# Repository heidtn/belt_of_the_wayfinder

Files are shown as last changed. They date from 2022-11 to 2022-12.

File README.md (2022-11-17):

# belt of the wayfinder
This project is the design for a belt that uses vibrational motors to tell the wearer where north is.  This has been inspired by many similar projects in the past.  The basic concept is that by always knowing north, the wearer can gain an intuitive understanding of where north is and improve their sense of direction.

This project includes the PCB design, firmware, and mechanical assemblies.

CAD has been designed using Onshape and the link can be found [here](https://cad.onshape.com/documents/3174cd1b7d359cff45b60529/w/59155bcb796c6976c8cc7d48/e/c52ae8d364edc915756cc2c3)

As of this commit, the firmware and hardware have not yet been tested and development is still underway.

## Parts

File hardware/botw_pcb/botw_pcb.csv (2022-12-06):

Value | Reference(s) | Footprint | JLCPCB Part #
1u | C1 | Capacitor_SMD:C_0603_1608Metric | C15849
10u | C2, C4, C5, C6, C7, C8, C9, C10, C16 | Capacitor_SMD:C_0603_1608Metric | C19702
0.1u | C3 | Capacitor_SMD:C_0603_1608Metric | C14663
220n | C11 | Capacitor_SMD:C_0603_1608Metric | C21120
100n | C12, C13, C14, C15 | Capacitor_SMD:C_0603_1608Metric | C14663
1N4148 | D1, D2, D4, D5, D6, D7, D8, D9 | Diode_SMD:D_SOD-123 | C81598
LED | D3 | LED_SMD:LED_0603_1608Metric | C165982
LED | D10 | LED_SMD:LED_0603_1608Metric | C138547
LED | D11 | LED_SMD:LED_0603_1608Metric | C138545
2.2u | L1 | Inductor_SMD:L_0805_2012Metric | C1043
USB_C_Plug_USB2.0 | P1 | Connector_USB:USB_C_Receptacle_HRO_TYPE-C-31-M-12 | C165948
S8050 | Q1, Q2, Q3, Q4, Q5, Q6, Q7, Q8, Q9 | Package_TO_SOT_SMD:SOT-23 | C2146
300 | R1, R4 | Resistor_SMD:R_0603_1608Metric | C23025
2k | R2 | Resistor_SMD:R_0603_1608Metric | C22975
100 | R3, R5 | Resistor_SMD:R_0603_1608Metric | C22775
200 | R6, R7 | Resistor_SMD:R_0603_1608Metric | C8218
2k2 | R8, R9, R10, R11, R12, R13, R14, R15, R18 | Resistor_SMD:R_0603_1608Metric | C4190
10k | R16, R17 | Resistor_SMD:R_0603_1608Metric | C25804
4k7 | R19, R20 | Resistor_SMD:R_0603_1608Metric | C23162
AAP2154 | U1 | custom_footprints:TSOT-25 | C370749
TPS63001 | U2 | Package_SON:Texas_DRC0010J_ThermalVias | C28060
STM32F030CCTx | U3 | Package_QFP:LQFP-48_7x7mm_P0.5mm | C81787
LIS2MDLTR | U4 | Package_LGA:LGA-12_2x2mm_P0.5mm | C919695
LSM6DS3 | U5 | Package_LGA:LGA-14_3x2.5mm_P0.5mm_LayoutBorder3x4y | C967633

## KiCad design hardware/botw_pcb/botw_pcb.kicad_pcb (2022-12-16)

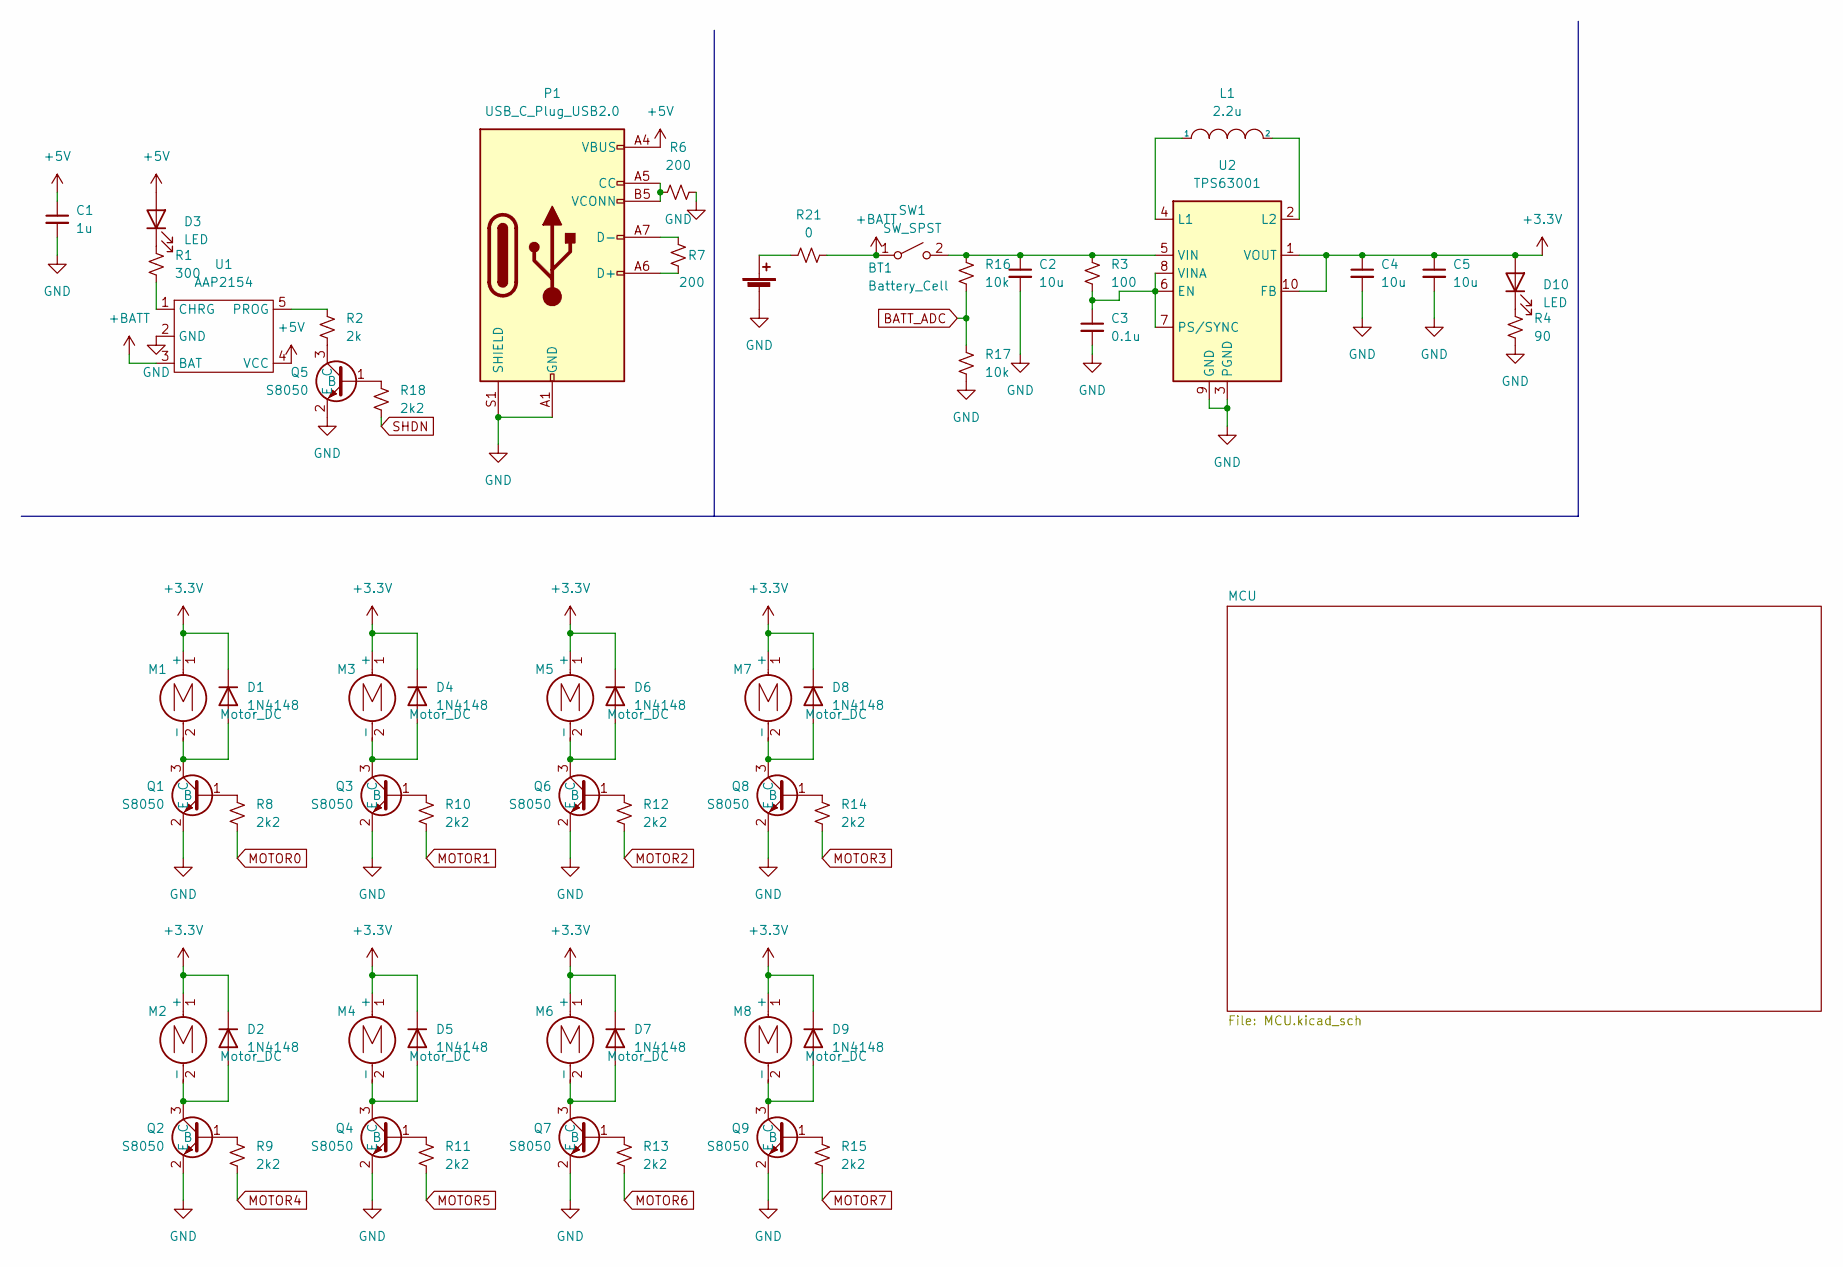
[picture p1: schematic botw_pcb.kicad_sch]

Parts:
BT1: Battery_Cell; PinHeader_1x02_P2.54mm_Vertical
C1: 1u; C_0603_1608Metric
C2, C4, C5: 10u; C_0603_1608Metric
C3: 0.1u; C_0603_1608Metric
D1, D2, D4, D5, D6, D7, D8, D9: 1N4148; D_SOD-123
D3, D10: LED; LED_0603_1608Metric
L1: 2.2u; L_0805_2012Metric
M1, M2, M3, M4, M5, M6, M7, M8: Motor_DC; PinHeader_1x02_P2.54mm_Vertical
P1: USB_C_Plug_USB2.0; USB_C_Receptacle_HRO_TYPE-C-31-M-12
Q1, Q2, Q3, Q4, Q5, Q6, Q7, Q8, Q9: S8050; SOT-23
R1: 300; R_0603_1608Metric
R2: 2k; R_0603_1608Metric
R3: 100; R_0603_1608Metric
R4: 90; R_0603_1608Metric
R6, R7: 200; R_0603_1608Metric
R8, R9, R10, R11, R12, R13, R14, R15, R18: 2k2; R_0603_1608Metric
R16, R17: 10k; R_0603_1608Metric
R21: 0; R_0603_1608Metric
SW1: SW_SPST; PinSocket_1x02_P2.54mm_Vertical
U1: AAP2154; TSOT-25
U2: TPS63001; Texas_DRC0010J_ThermalVias

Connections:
+3.3V: C4.1, C5.1, D1.1 (K), D2.1 (K), D4.1 (K), D5.1 (K), D6.1 (K), D7.1 (K), D8.1 (K), D9.1 (K), D10.2 (A), M1.1 (+), M2.1 (+), M3.1 (+), M4.1 (+), M5.1 (+), M6.1 (+), M7.1 (+), M8.1 (+), U2.1 (VOUT), U2.10 (FB); also elsewhere on the board
+5V: C1.1, D3.2 (A), P1.A4 (VBUS), P1.A9 (VBUS), P1.B4 (VBUS), P1.B9 (VBUS), U1.4 (VCC)
+BATT: R21.2, SW1.1 (A), U1.3 (BAT)
BATT_ADC: R16.2, R17.1; also elsewhere on the board
GND: BT1.2 (-), C1.2, C2.2, C3.2, C4.2, C5.2, P1.A1 (GND), P1.A12 (GND), P1.B1 (GND), P1.B12 (GND), P1.S1 (SHIELD), Q1.2 (E), Q2.2 (E), Q3.2 (E), Q4.2 (E), Q5.2 (E), Q6.2 (E), Q7.2 (E), Q8.2 (E), Q9.2 (E), R4.2, R6.2, R17.2, U1.2 (GND), U2.3 (PGND), U2.9 (GND), U2.11 (PGND); also elsewhere on the board
MOTOR0: R8.2; also elsewhere on the board
MOTOR1: R10.2; also elsewhere on the board
MOTOR2: R12.2; also elsewhere on the board
MOTOR3: R14.2; also elsewhere on the board
MOTOR4: R9.2; also elsewhere on the board
MOTOR5: R11.2; also elsewhere on the board
MOTOR6: R13.2; also elsewhere on the board
MOTOR7: R15.2; also elsewhere on the board
unnamed: BT1.1 (+), R21.1
unnamed: C2.1, R3.1, R16.1, SW1.2 (B), U2.5 (VIN)
unnamed: C3.1, R3.2, U2.6 (EN), U2.7 (PS/SYNC), U2.8 (VINA)
unnamed: D1.2 (A), M1.2 (-), Q1.3 (C)
unnamed: D2.2 (A), M2.2 (-), Q2.3 (C)
unnamed: D3.1 (K), R1.1
unnamed: D4.2 (A), M3.2 (-), Q3.3 (C)
unnamed: D5.2 (A), M4.2 (-), Q4.3 (C)
unnamed: D6.2 (A), M5.2 (-), Q6.3 (C)
unnamed: D7.2 (A), M6.2 (-), Q7.3 (C)
unnamed: D8.2 (A), M7.2 (-), Q8.3 (C)
unnamed: D9.2 (A), M8.2 (-), Q9.3 (C)
unnamed: D10.1 (K), R4.1
unnamed: L1.1, U2.4 (L1)
unnamed: L1.2, U2.2 (L2)
unnamed: P1.A5 (CC), P1.B5 (VCONN), R6.1
unnamed: P1.A6 (D+), R7.2
unnamed: P1.A7 (D-), R7.1
unnamed: R1.2, U1.1 (CHRG)
unnamed: R2.1, U1.5 (PROG)
unnamed: Q5.3 (C), R2.2
unnamed: Q1.1 (B), R8.1
unnamed: Q2.1 (B), R9.1
unnamed: Q3.1 (B), R10.1
unnamed: Q4.1 (B), R11.1
unnamed: Q6.1 (B), R12.1
unnamed: Q7.1 (B), R13.1
unnamed: Q8.1 (B), R14.1
unnamed: Q9.1 (B), R15.1
unnamed: Q5.1 (B), R18.1
SHDN: R18.2; also elsewhere on the board

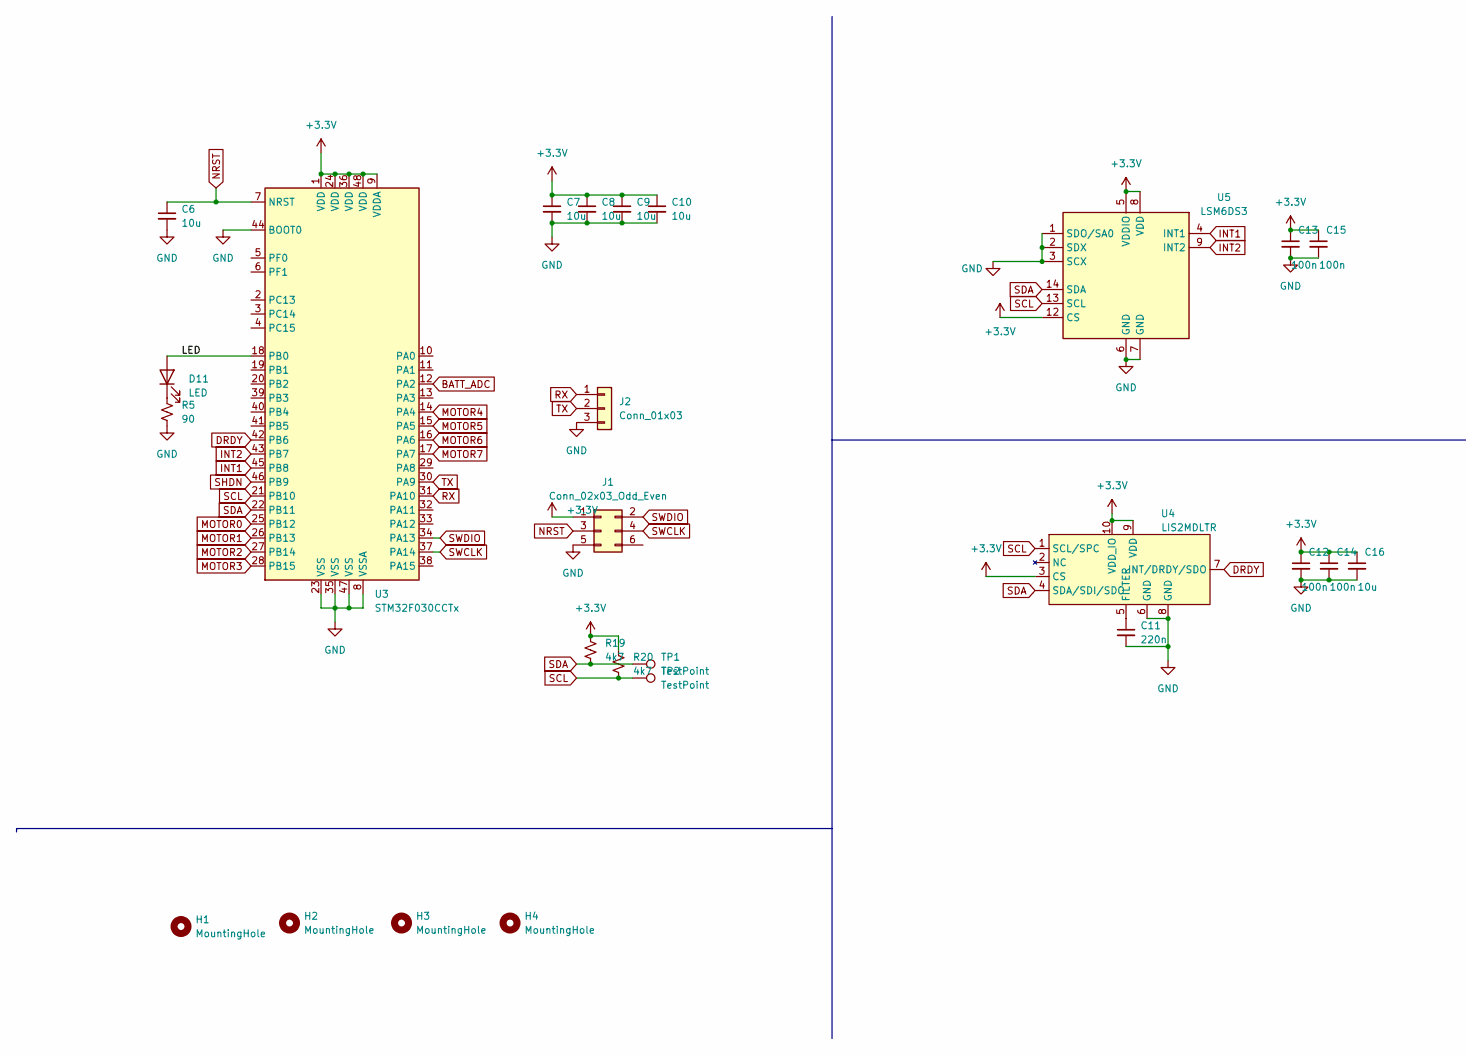
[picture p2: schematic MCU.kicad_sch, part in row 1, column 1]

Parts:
C6, C7, C8, C9, C10, C16: 10u; C_0603_1608Metric
C11: 220n; C_0603_1608Metric
C12, C13, C14, C15: 100n; C_0603_1608Metric
D11: LED; LED_0603_1608Metric
H1, H2, H3, H4: MountingHole; MountingHole_2.7mm_M2.5
J1: Conn_02x03_Odd_Even; Tag-Connect_TC2030-IDC-FP_2x03_P1.27mm_Vertical
J2: Conn_01x03; PinHeader_1x03_P2.54mm_Vertical
R5: 90; R_0603_1608Metric
R19, R20: 4k7; R_0603_1608Metric
TP1, TP2: TestPoint; TestPoint_Pad_D1.0mm
U3: STM32F030CCTx; LQFP-48_7x7mm_P0.5mm
U4: LIS2MDLTR; LGA-12_2x2mm_P0.5mm
U5: LSM6DS3; LGA-14_3x2.5mm_P0.5mm_LayoutBorder3x4y

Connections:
+3.3V: C7.1, C8.1, C9.1, C10.1, C12.1, C13.1, C14.1, C15.1, C16.1, J1.1, R19.1, R20.1, U3.1 (VDD), U3.9 (VDDA), U3.24 (VDD), U3.36 (VDD), U3.48 (VDD), U4.3 (CS), U4.9 (VDD), U4.10 (VDD_IO), U5.5 (VDDIO), U5.8 (VDD), U5.12 (CS); also elsewhere on the board
/MCU/LED: D11.2 (A), U3.18 (PB0)
BATT_ADC: U3.12 (PA2); also elsewhere on the board
DRDY: U3.42 (PB6), U4.7 (INT/DRDY/SDO)
GND: C6.2, C7.2, C8.2, C9.2, C10.2, C11.2, C12.2, C13.2, C14.2, C15.2, C16.2, J1.5, J2.3, R5.2, U3.8 (VSSA), U3.23 (VSS), U3.35 (VSS), U3.44 (BOOT0), U3.47 (VSS), U4.6 (GND), U4.8 (GND), U5.1 (SDO/SA0), U5.2 (SDX), U5.3 (SCX), U5.6 (GND), U5.7 (GND); also elsewhere on the board
INT1: U3.45 (PB8), U5.4 (INT1)
INT2: U3.43 (PB7), U5.9 (INT2)
MOTOR0: U3.25 (PB12); also elsewhere on the board
MOTOR1: U3.26 (PB13); also elsewhere on the board
MOTOR2: U3.27 (PB14); also elsewhere on the board
MOTOR3: U3.28 (PB15); also elsewhere on the board
MOTOR4: U3.14 (PA4); also elsewhere on the board
MOTOR5: U3.15 (PA5); also elsewhere on the board
MOTOR6: U3.16 (PA6); also elsewhere on the board
MOTOR7: U3.17 (PA7); also elsewhere on the board
NRST: C6.1, J1.3, U3.7 (NRST)
unnamed: C11.1, U4.5 (FILTER)
unnamed: D11.1 (K), R5.1
RX: J2.1, U3.31 (PA10)
SCL: R20.2, TP2.1, U3.21 (PB10), U4.1 (SCL/SPC), U5.13 (SCL)
SDA: R19.2, TP1.1, U3.22 (PB11), U4.4 (SDA/SDI/SDO), U5.14 (SDA)
SHDN: U3.46 (PB9); also elsewhere on the board
SWCLK: J1.4, U3.37 (PA14)
SWDIO: J1.2, U3.34 (PA13)
TX: J2.2, U3.30 (PA9)

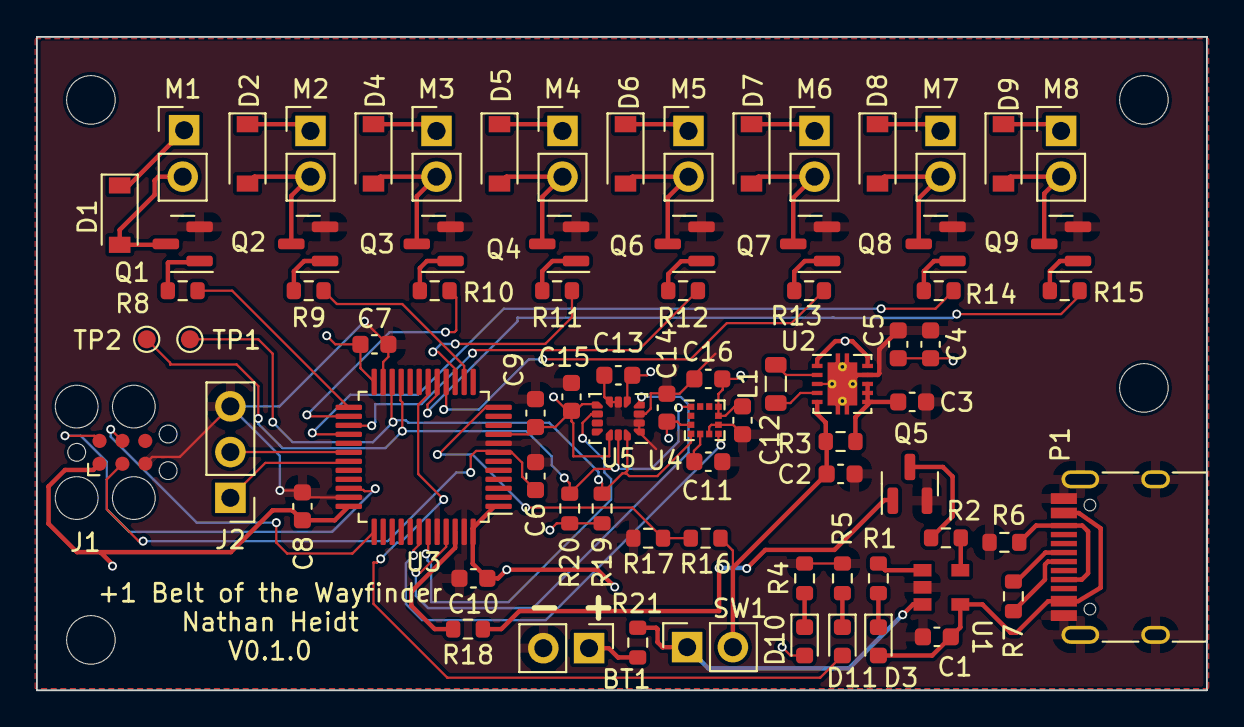
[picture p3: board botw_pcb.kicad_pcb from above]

Board: 2 copper layers, 65.0 x 36.3 mm, 82 parts (0 on the bottom side), 57 nets.

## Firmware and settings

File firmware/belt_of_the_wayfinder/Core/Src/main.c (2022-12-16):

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
/* Includes ------------------------------------------------------------------*/
#include "main.h"
#include "adc.h"
#include "i2c.h"
#include "tim.h"
#include "usart.h"
#include "gpio.h"

/* USER CODE BEGIN Includes */
#include <stdio.h>
#include <math.h>

/* USER CODE END Includes */


/* USER CODE BEGIN PV */


typedef struct {
	float x;
	float y;
} compass_vector_t;


typedef struct __attribute__((packed)) {
	int16_t X;
	int16_t Y;
	int16_t Z;
} magnetometer_reading_t;

typedef enum {
	SINGLE_BLINK,
	DOUBLE_BLINK,
} blink_type_t;

// register definitions
#define MAG_I2C_ID (0x1E << 1)
#define MAG_REG_CFG_A (0x60)
#define MAG_REG_CFG_C (0x62)
#define MAG_REG_OFFSETX_L (0x45)
#define MAG_REG_OUTX_L (0x68)

#define IMU_I2C_ID (0x6A << 1)
#define IMU_REG_WHOAMI (0x0F)
#define IMU_REG_MD1_CFG (0x5E)
#define IMU_REG_TAP_CFG (0x58)
#define IMU_REG_CTRL1_XL (0x10)
#define IMU_REG_TAPSRC (0x1C)
#define IMU_REG_FUNC_CFG_ACCESS (0x01)
#define IMU_REG_FIFO_CTRL5 (0x0A)

#define IMU_MD1_CFG (0b00001000)
#define IMU_TAP_CFG (0b10001111)  // TODO remove last bit as latch
#define IMU_CTRL1_XL (0b01000000)
#define IMU_FUNC_CFG_ACCESS (0b10100000)
#define IMU_FIFO_CTRL5 (0b00100110)

static magnetometer_reading_t mag_offset = {
	.X = -136,
	.Y = -352,
	.Z = -216
};

GPIO_TypeDef* motor_ports[] = {GPIOB, GPIOB, GPIOB, GPIOB, GPIOA, GPIOA, GPIOA, GPIOA};
uint16_t motor_pins[] = {GPIO_PIN_12, GPIO_PIN_13, GPIO_PIN_14, GPIO_PIN_15, GPIO_PIN_4, GPIO_PIN_5, GPIO_PIN_6, GPIO_PIN_7};
unsigned int target_buzzer = 0;

#define LED_PORT GPIOB
#define LED_PIN GPIO_PIN_0

/* USER CODE END PV */

void SystemClock_Config(void);
/* USER CODE BEGIN PFP */

static void init_mag(void);
static void init_imu(void);
static void get_compass_direction(compass_vector_t *direction);
static void set_buzzers(compass_vector_t *direction);
static void error_blink(blink_type_t blink_type);
static void set_mag_offset(void);
static void motor_test(void);
static void configure_charger(void);
static void configure_motors(void);

/* USER CODE END PFP */

/**
  * @brief  The application entry point.
  * @retval int
  */
int main(void)
{
  /* MCU Configuration--------------------------------------------------------*/

  /* Reset of all peripherals, Initializes the Flash interface and the Systick. */
  HAL_Init();

  /* Configure the system clock */
  SystemClock_Config();

  /* USER CODE BEGIN SysInit */
/*
  HAL_NVIC_DisableIRQ(SysTick_IRQn);
  HAL_SYSTICK_CLKSourceConfig(SYSTICK_CLKSOURCE_HCLK);
  HAL_SYSTICK_Config(HAL_RCC_GetHCLKFreq()/1000);
  HAL_NVIC_EnableIRQ(SysTick_IRQn);
*/

  /* USER CODE END SysInit */

  /* Initialize all configured peripherals */
  MX_GPIO_Init();
  MX_ADC_Init();
  MX_I2C2_Init();
  MX_USART1_UART_Init();
  MX_TIM16_Init();
  /* USER CODE BEGIN 2 */
  char *start_string = "belt system initialized!\n";
  HAL_UART_Transmit(&huart1, start_string, sizeof(start_string), 1000);
  /* USER CODE END 2 */

  /* Infinite loop */
  /* USER CODE BEGIN WHILE */
  // nice linky: https://www.youtube.com/watch?v=VfbW6nfG4kw
  // may need to set NVIC enable on the IRQ for the timer: https://electronics.stackexchange.com/questions/544797/output-compares-triggering-function-not-work-on-stm32

  compass_vector_t direction;
  init_mag();
  set_mag_offset();
  init_imu();
  configure_motors();
  configure_charger();
  //motor_test();

  HAL_TIM_Base_Start_IT(&htim16);


  while (1)
  {
	get_compass_direction(&direction);
	configure_motors();
	//set_buzzers(&direction);
	HAL_Delay(500);

    /* USER CODE END WHILE */

    /* USER CODE BEGIN 3 */
  }
  /* USER CODE END 3 */
}

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
/* USER CODE BEGIN 4 */

static void init_mag(void) {
	// nominal startup, consult the datasheet
	uint8_t cfga_nominal[] = {0x80};
	uint8_t cfgc_nominal[] = {0x01};

	HAL_StatusTypeDef stat_a = HAL_I2C_Mem_Write(&hi2c2, MAG_I2C_ID, MAG_REG_CFG_A, 1, cfga_nominal, sizeof(cfga_nominal), 1000);
	HAL_StatusTypeDef stat_c = HAL_I2C_Mem_Write(&hi2c2, MAG_I2C_ID, MAG_REG_CFG_C, 1, cfgc_nominal, sizeof(cfga_nominal), 1000);

	if(stat_a != HAL_OK || stat_c != HAL_OK) {
		error_blink(DOUBLE_BLINK);
	}
}

static void set_mag_offset(void) {
	HAL_StatusTypeDef stat_a = HAL_I2C_Mem_Write(&hi2c2, MAG_I2C_ID, MAG_REG_OFFSETX_L, 1, &mag_offset, sizeof(mag_offset), 1000);
}

static HAL_StatusTypeDef imu_write_reg(uint8_t reg, uint8_t value) {
	uint8_t val[] = {value};
	HAL_StatusTypeDef stat = HAL_I2C_Mem_Read(&hi2c2, IMU_I2C_ID, reg, 1, val, sizeof(val), 1000);
	return stat;
}

static void init_imu(void) {
	uint8_t ID[] = {0x00};
	HAL_StatusTypeDef stat = HAL_I2C_Mem_Read(&hi2c2, IMU_I2C_ID, IMU_REG_WHOAMI, 1, ID, sizeof(ID), 1000);

	HAL_StatusTypeDef stat_md1 = imu_write_reg(IMU_REG_MD1_CFG, IMU_MD1_CFG);
	HAL_StatusTypeDef stat_tap = imu_write_reg(IMU_REG_TAP_CFG, IMU_TAP_CFG);
	HAL_StatusTypeDef stat_nom = imu_write_reg(IMU_REG_CTRL1_XL, IMU_CTRL1_XL);
	HAL_StatusTypeDef stat_fifo = imu_write_reg(IMU_REG_FIFO_CTRL5, IMU_FIFO_CTRL5);

	if((stat | stat_md1 | stat_tap | stat_nom ) != HAL_OK) {
		error_blink(DOUBLE_BLINK);
	}
}

static void error_blink(blink_type_t blink_type) {
	switch(blink_type) {
		case DOUBLE_BLINK:
			HAL_GPIO_WritePin(LED_PORT, LED_PIN, GPIO_PIN_SET);
			HAL_Delay(250);
			HAL_GPIO_WritePin(LED_PORT, LED_PIN, GPIO_PIN_RESET);
			HAL_Delay(250);
			HAL_GPIO_WritePin(LED_PORT, LED_PIN, GPIO_PIN_SET);
			HAL_Delay(250);
			HAL_GPIO_WritePin(LED_PORT, LED_PIN, GPIO_PIN_RESET);
			break;
		default:
			break;
	}
}

static void get_compass_direction(compass_vector_t *direction) {
	static magnetometer_reading_t reading;
	HAL_I2C_Mem_Read(&hi2c2, MAG_I2C_ID, MAG_REG_OUTX_L, 1, (uint8_t *)&reading, sizeof(reading), HAL_MAX_DELAY);

	// lazy change of coordinate frames, probably wrong
	direction->x = (float)reading.X;
	direction->y = (float)reading.Z;
	float x = direction->x;
	float y = direction->y;

	// bad cohesion!  Probably break this stuff out into vector management functions
	float length = sqrt(x*x + y*y);
	if(abs(length) < 0.001) {
		direction->y = 1.0;
		direction->x = 0.0;
	} else {
		direction->x /= length;
		direction->y /= length;
	}

	static char message[64];
	int string_length = sprintf(message, "Got new reading: %f %f\n", direction->x, direction->y);
	HAL_UART_Transmit(&huart1, message, string_length, HAL_MAX_DELAY);
}


static void set_buzzers(compass_vector_t *direction) {
	// pick a buzzer based on the direction.

	// make angle from 0 to 8 with wrapping
	// in a better world, this wouldn't be coupled to the number of motors, but am lazy...
	float angle = (atan2(direction->x, direction->y) / (2.0*3.14159)) * 8.0;
	unsigned int new_target = 0;
	if(angle < 0.5 || angle > 7.5) {
		new_target = 0;
	} else {
		new_target = (unsigned int)(angle + 0.5);
	}
	HAL_TIM_Base_Stop_IT(&htim16);
	// probably clear timer or something
	HAL_GPIO_WritePin(motor_ports[target_buzzer], motor_pins[target_buzzer], GPIO_PIN_RESET);
	target_buzzer = new_target;
	HAL_TIM_Base_Start_IT(&htim16);

	static char message[64];
	int string_length = sprintf(message, "Setting motor: %d\n", new_target);
	HAL_UART_Transmit(&huart1, message, string_length, HAL_MAX_DELAY);
}

static void motor_test(void) {
	int num_motors = sizeof(motor_ports) / sizeof(motor_ports[0]);
	for(int i = 0; i < num_motors; i++) {
		HAL_GPIO_WritePin(motor_ports[i], motor_pins[i], GPIO_PIN_SET);
		HAL_Delay(100);
		HAL_GPIO_WritePin(motor_ports[i], motor_pins[i], GPIO_PIN_RESET);
		HAL_Delay(100);
	}
}

static void configure_motors(void) {
	int num_motors = sizeof(motor_ports) / sizeof(motor_ports[0]);
	for(int i = 0; i < num_motors; i++) {
		//HAL_GPIO_WritePin(motor_ports[i], motor_pins[i], GPIO);
		HAL_GPIO_TogglePin(motor_ports[i], motor_pins[i]);
	}
}

static void configure_charger(void) {
	HAL_GPIO_WritePin(SHDN_GPIO_Port, SHDN_Pin, GPIO_PIN_SET);
}

void HAL_TIM_PeriodElapsedCallback(TIM_HandleTypeDef *htim) {
	if(htim == &htim16) {

		//HAL_GPIO_WritePin(motor_ports[target_buzzer], motor_pins[target_buzzer], GPIO_PIN_SET);
	}
}

void HAL_TIM_OC_DelayElapsedCallback(TIM_HandleTypeDef *htim) {
	if(htim == &htim16) {
		//HAL_GPIO_WritePin(motor_ports[target_buzzer], motor_pins[target_buzzer], GPIO_PIN_RESET);
	}
}

void HAL_GPIO_EXTI_Callback(uint16_t GPIO_Pin) {
	//HAL_GPIO_TogglePin(LED_PORT, LED_PIN);
}

/* USER CODE END 4 */
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


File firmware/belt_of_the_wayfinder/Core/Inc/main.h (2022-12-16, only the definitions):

#define MOTOR4_Pin GPIO_PIN_4
#define MOTOR4_GPIO_Port GPIOA
#define MOTOR5_Pin GPIO_PIN_5
#define MOTOR5_GPIO_Port GPIOA
#define MOTOR6_Pin GPIO_PIN_6
#define MOTOR6_GPIO_Port GPIOA
#define MOTOR7_Pin GPIO_PIN_7
#define MOTOR7_GPIO_Port GPIOA
#define MOTOR0_Pin GPIO_PIN_12
#define MOTOR0_GPIO_Port GPIOB
#define MOTOR1_Pin GPIO_PIN_13
#define MOTOR1_GPIO_Port GPIOB
#define MOTOR2_Pin GPIO_PIN_14
#define MOTOR2_GPIO_Port GPIOB
#define MOTOR3_Pin GPIO_PIN_15
#define MOTOR3_GPIO_Port GPIOB
#define SHDN_Pin GPIO_PIN_9
#define SHDN_GPIO_Port GPIOB

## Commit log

2022-11-17 Initial commit, basic belt design and firmware
    [MCU.kicad_sch, botw_pcb.kicad_pcb, botw_pcb.kicad_sch]
2022-12-04 Added pullups to I2C'
    [MCU.kicad_sch, botw_pcb.kicad_pcb, botw_pcb.kicad_sch]
2022-12-06 Changed to a new part for mag
    [MCU.kicad_sch, botw_pcb.csv, botw_pcb.kicad_pcb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]
2022-12-16 Transistor footprint was wrong, whoops! Also added in hard iron correction
    [botw_pcb.kicad_pcb, botw_pcb.kicad_sch]
2022-12-16 Hard iron correction in firmware and early work on other features
    [belt_of_the_wayfinder.ioc, main.c]

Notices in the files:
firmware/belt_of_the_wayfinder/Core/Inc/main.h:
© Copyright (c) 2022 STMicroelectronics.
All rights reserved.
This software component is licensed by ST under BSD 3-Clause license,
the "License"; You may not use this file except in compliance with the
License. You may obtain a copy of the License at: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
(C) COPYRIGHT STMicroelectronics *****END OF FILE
